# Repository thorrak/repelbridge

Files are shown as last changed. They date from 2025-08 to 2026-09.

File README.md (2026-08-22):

# RepelBridge - Cloud-free Mosquito Repelling

An ESP32-based controller that manages Thermacell Liv Repeller devices over WiFi without using the cloud. 

**NOTE** - This is an independent, third party project, and is not affiliated with Thermacell in any way. Thermacell and Thermacell LIV are trademarks of Thermacell Repellents, Inc. 

## Features

### Cloud Free
- Works entirely locally
- Integrates with Home Assistant over WiFi

### Dual Bus Support
- Independent control of two sets of up to five repellers
- Create "zones" of repellers that are controlled independently of one another

### Device Management
- Automatic device discovery and addressing (including for brand new devices)
- RGB LED color control and brightness adjustment
- Cartridge usage tracking and monitoring (WiFi only, see "limitations" below)
- Configurable auto-shutoff timers & cartridge warn timers

### Multi-Mode Operation
- **WiFi Mode**: Web-based REST API control for Home Assistant integration
- **Sniffer Mode**: Passive monitoring of RS-485 communications (for development)

### 100% Free & Open Source
- Open source firmware
- Open source hardware
- Open source Home Assistant integration
- All 100% free, and licensed under the (Apache 2.0 license)[LICENSE]

## Limitations

The communication protocol was reverse engineered from the official controller, and is not complete. Known to be missing is the built in "end of cartridge life" blinking, but other features not identified 

## Hardware

### Required Components
- **ESP32-S3 Microcontroller** - [ESP32-S3](https://www.seeedstudio.com/XIAO-ESP32S3-p-5627.html) recommended
- **Assembled RepelBridge PCB** - Design files available in this repo, including complete Bill of Materials. See [build guide](BUILDING.md) for details.
- **1x or 2x M12 4-pin A-coded Female Jacks** - [These](https://www.amazon.com/Waterproof-Connector-Bulkhead-Straight-Receptacle/dp/B0BVZDQYH5) or similar
- **Power Cable** - Standard [AC power cable](https://www.amazon.com/dp/B07C9D6CXY) of the appropriate length
- **Enclosure** - The one I used is [this one](https://www.amazon.com/dp/B0D97GQRGX), see [build guide](BUILDING.md) for more info

For complete build instructions, see the [build guide](BUILDING.md). 

For my build, material cost excluding shipping/taxes was appx. $97.14 per controller (each of which can manage two banks of repellers)

### Pin Connections (Xiao ESP32-S3)

#### Bus 0 (Primary)
- MAX3485 A/B → RS-485 bus 0 differential pair
- RO (Receive) → GPIO44 (UART RX)
- DI (Driver) → GPIO43 (UART TX)
- DE/RE (tied) → GPIO6 (Direction control)
- Power control → GPIO9

#### Bus 1 (Secondary)
- MAX3485 A/B → RS-485 bus 1 differential pair
- RO (Receive) → GPIO5
- DI (Driver) → GPIO7
- DE/RE (tied) → GPIO4 (Direction control)
- Power control → GPIO8

Pin assignments are defined as `BUS_X_*_PIN` build flags in [platformio.ini](platformio.ini) and can be overridden there.

### Communication Specs
- **Baud Rate**: 19,200
- **Format**: 8N1 (8 data bits, no parity, 1 stop bit)
- **Protocol**: RS-485 differential signaling
- **Packet Size**: 11 bytes fixed

## Building

### Prerequisites
- [PlatformIO](https://platformio.org/) installed
- ESP-IDF toolchain (fetched automatically by PlatformIO)
- Git for cloning dependencies

### Build Environment

The project ships a single PlatformIO environment targeting the Seeed XIAO ESP32-S3 with the ESP-IDF framework:

```bash
pio run -e esp32-s3-wifi
```

### Dependencies
Automatically managed by PlatformIO:
- `thorrak/esp_wifi_config` for WiFi provisioning (captive portal / Network Provisioning over BLE)
- `bblanchon/ArduinoJson` for REST API responses
- LittleFS (via ESP-IDF) for persistent settings storage

## Flashing

### Initial Flash
1. Connect the XIAO ESP32-S3 to your computer via USB-C
2. Build and upload firmware:
   ```bash
   pio run -e esp32-s3-wifi -t upload
   ```
3. Monitor serial output:
   ```bash
   pio device monitor -e esp32-s3-wifi
   ```

### WiFi Setup (First Boot)
1. Device creates WiFi access point: `RepelBridgeAP`
2. Connect to AP using password: `repelbridge`
3. Configure your WiFi network via captive portal (BLE provisioning is also supported)
4. Device will restart and connect to your network

### Mode Selection
Operational mode is selected at compile time via build flags in [platformio.ini](platformio.ini). The shipped `esp32-s3-wifi` environment defines `MODE_WIFI_CONTROLLER`. Alternate modes (`MODE_SNIFFER`, `MODE_CONTROLLER`) are still supported in the source and can be enabled by swapping the build flag.

## Home Assistant Integration

### Automatic Discovery
- Device advertises via mDNS as `_repelbridge._tcp.local.`
- Appears in Home Assistant as discovered integration
- Alternatively, manually add using device IP address

### Entities Created
For each bus (0 and 1):

**Light Entities**
- `light.repelbridge_bus_0` - RGB color and brightness control
- `light.repelbridge_bus_1` - RGB color and brightness control

**Switch Entities**
- `switch.repelbridge_bus_0_power` - Power on/off control
- `switch.repelbridge_bus_1_power` - Power on/off control

**Sensor Entities**
- `sensor.repelbridge_bus_0_runtime_hours` - Cartridge usage hours
- `sensor.repelbridge_bus_0_cartridge_life` - Remaining cartridge life %
- `sensor.repelbridge_bus_0_device_count` - Connected repeller count

**Configuration Entities**
- `number.repelbridge_bus_0_auto_shutoff` - Auto shutoff timer (seconds)
- `number.repelbridge_bus_0_cartridge_warning` - Cartridge warning threshold (hours)

### Services
- `repelbridge.reset_cartridge` - Reset cartridge runtime tracking

## Automation Examples

### Low Cartridge Warning

```yaml
automation:
  - alias: "RepelBridge Low Cartridge Warning"
    trigger:
      platform: numeric_state
      entity_id: sensor.repelbridge_bus_0_cartridge_life
      below: 10
    action:
      service: notify.mobile_app_your_phone
      data:
        message: "RepelBridge Bus 0 cartridge is running low ({{ states('sensor.repelbridge_bus_0_cartridge_life') }}% remaining)"
```

### Daily Schedule

```yaml
automation:
  - alias: "RepelBridge Daily Schedule"
    trigger:
      platform: time
      at: "20:00:00"
    action:
      - service: light.turn_on
        target:
          entity_id: light.repelbridge_bus_0
        data:
          rgb_color: [0, 213, 255]  # Cyan-blue
          brightness: 200
  
  - alias: "RepelBridge Turn Off"
    trigger:
      platform: time
      at: "06:00:00"
    action:
      service: light.turn_off
      target:
        entity_id: light.repelbridge_bus_0
```

### REST API Endpoints

Direct API access available at `http://device-ip/`:

**System Information**
- `GET /api/system/status` - Device status, uptime, WiFi info

**Bus Control** (replace `{0,1}` with bus number)
- `GET /api/bus/{0,1}/status` - Bus state and current settings
- `POST /api/bus/{0,1}/power` - Power control (JSON: `{"state": true/false}`)
- `POST /api/bus/{0,1}/brightness` - Brightness (JSON: `{"value": 0-255}`)
- `POST /api/bus/{0,1}/color` - RGB color (JSON: `{"red": 0-255, "green": 0-255, "blue": 0-255}`)

**Cartridge Management**
- `GET /api/bus/{0,1}/cartridge` - Usage stats and remaining life
- `POST /api/bus/{0,1}/cartridge/reset` - Reset runtime counter
- `GET /api/bus/{0,1}/auto_shutoff` - Get current auto-shutoff timer in minutes
- `POST /api/bus/{0,1}/auto_shutoff` - Set auto-shutoff timer (JSON: `{"minutes": 0-960}`)
- `GET /api/bus/{0,1}/warn_at` - Get current cartridge warning threshold in hours
- `POST /api/bus/{0,1}/warn_at` - Set warning threshold (JSON: `{"hours": 0-9999}`)

## Troubleshooting

### Device Not Discovered
- Ensure device is on the same network
- Check device is in WiFi mode (`MODE_WIFI_CONTROLLER`)
- Verify mDNS service `_repelbridge._tcp.local.` is broadcast

### Connection Issues
- Verify IP address is correct
- Check device web interface is accessible at `http://device-ip/api/system/status`
- Ensure firewall allows HTTP traffic on port 80

### Entity Updates
- Default update interval is 30 seconds
- Entities update automatically after control commands
- Check Home Assistant logs for API communication errors

## Support

For issues and feature requests, please use the GitHub repository issue tracker.

## License

This integration is provided under the Apache 2.0 license.

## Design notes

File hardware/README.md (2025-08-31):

# Hardware Source Files

This directory contains the hardware source files for a RepelBridge build.

## Assembly Template

To make assembling the enclosure easier, I created a very basic [Enclosure Hole Template](./Enclosure%20Hole%20Template.pdf) which can be printed and provides a 1:1 guide for where the holes should be drilled on the face of the enclosure.

Use of this template is optional, but I found it helpful.

## JLCPCB Fabrication Files

The files needed to order a fully assembled RepelBridge from [JLCPCB](https://jlcpcb.com/) are available in the `JLCPCB Files` directory. This includes:

- Gerbers in RepelBridge.zip
- "Bill of Materials" in bom.csv with JLCPCB/LCSC part numbers
- "Pick and Place" positions file in positions.csv

These files should be ready for use to order a RepelBridge PCB from JLCPCB. Full instructions for using them are available in the [build guide](../BUILDING.md)

**NOTE about M4 Screws** - JLCMC [sells](https://jlcmc.com/product/s/E02/EDLA/FA-%E7%B4%A7%E5%9B%BA%E9%9B%B6%E4%BB%B6-%E8%9E%BA%E9%92%89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) M4x6mm screws which they will ship alongside your PCB for a very reasonable price if ordered at the same time. I **highly** recommend ordering these together with the PCB as the cost will likely be at least an order of magnitude lower than ordering separately from other sources. 

## KiCad Source Files

If you want to modify the PCB design (for example, to leverage a different enclosure) the source [KiCad](https://www.kicad.org/) files are available in the `KiCad Source` directory. 

**NOTE** - If you edit the PCB in KiCad and use the JLCPCB tools to export the BoM/PnP files, you will need to manually edit the BoM and PnP files to add the second female pin header for the microcontroller (U2) as it will not be automatically added/placed.

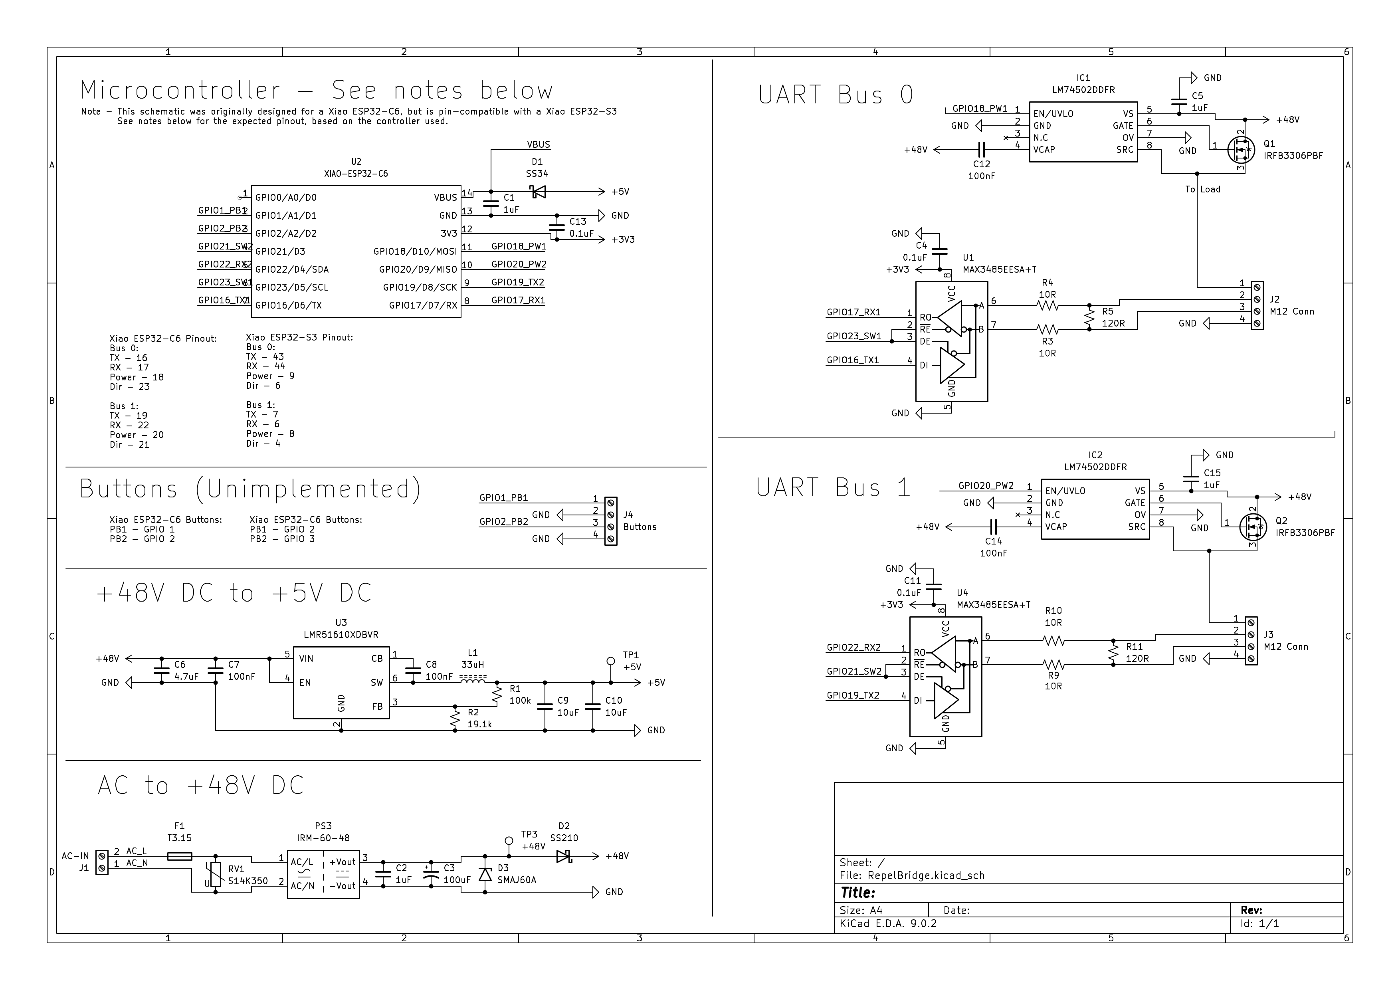
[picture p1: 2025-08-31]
img/schematic.png

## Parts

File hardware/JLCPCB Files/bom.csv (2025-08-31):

Designator | Footprint | Quantity | Value | LCSC Part #
C1 | 0603 | 1 | 1uF | C15849
C10, C9 | 0603 | 2 | 10uF | C19702
C11, C13, C4 | 0603 | 3 | 0.1uF | C14663
C12, C14, C7, C8 | 0805 | 4 | 100nF | C28233
C15, C2, C5 | 0805 | 3 | 1uF | C6119928
C3 | CP_Radial_D10.0mm_P5.00mm | 1 | 100uF | C2887235
C6 | 1210 | 1 | 4.7uF | C381466
D1 | D_SMA | 1 | SS34 | C8678
D2 | D_SMA | 1 | SS210 | C14996
D3 | D_SMA | 1 | SMAJ60A | C42394398
F1 | Fuse_8.5x4.0 | 1 | T3.15 | C354904
IC1, IC2 | SOT65P280X110-8N | 2 | LM74502DDFR | C3236215
J1 | TerminalBlock_Wuerth_691311400102_P7.62mm | 1 | AC-IN | C475104
J2, J3 | TerminalBlock_RND_205-00003_1x04_P5.00mm_Horizontal | 2 | M12 Conn | C3034542
J4 | TerminalBlock_RND_205-00003_1x04_P5.00mm_Horizontal | 1 | Buttons | C3034542
L1 | HPC8040NF | 1 | 33uH | C357084
PS3 | Converter_ACDC_MeanWell_IRM-60-xx_THT | 1 | IRM-60-48 | C5656542
Q1, Q2 | TO-220-3_Vertical | 2 | IRFB3306PBF | C2643
R1 | 0402 | 1 | 100k | C25741
R10, R3, R4, R9 | 0402 | 4 | 10R | C25077
R11, R5 | 0402 | 2 | 120R | C25079
R2 | 0402 | 1 | 19.1k | C52036
RV1 | RV_Disc_D15.5mm_W5.9mm_P7.5mm | 1 | S14K350 | C83535
TP1 | TestPoint_THTPad_D1.0mm_Drill0.5mm | 1 | +5V
TP3 | TestPoint_THTPad_D2.0mm_Drill1.0mm | 1 | +48V
U1, U4 | SOIC-8_3.9x4.9mm_P1.27mm | 2 | MAX3485EESA+T | C9943
U2,U2_2 | XIAO-ESP32C6-DIP | 1 | XIAO-ESP32-C6 | C25503116
U3 | SOT-23-6 | 1 | LMR51610XDBVR | C20539658

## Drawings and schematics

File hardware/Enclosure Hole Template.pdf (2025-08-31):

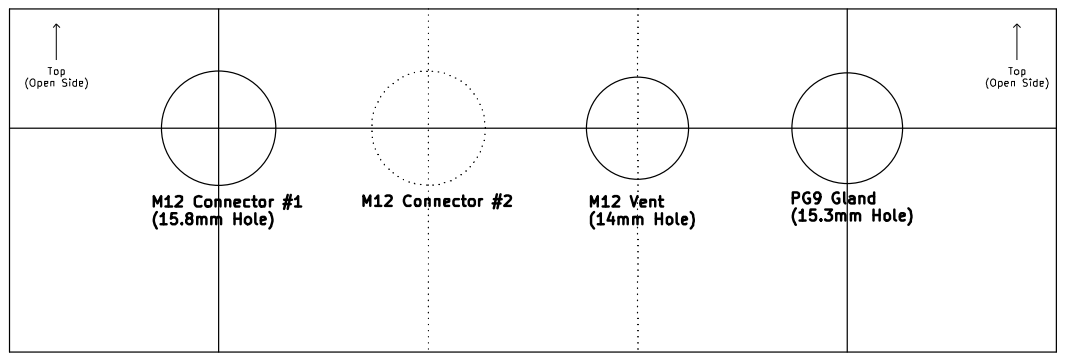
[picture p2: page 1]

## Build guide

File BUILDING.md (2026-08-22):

# Building a RepelBridge

## Introduction / About this Guide

This guide covers the steps that I used when building the RepelBridges that I have managing the Liv controllers in my home. Although most of the individual components I recommend can be replaced with similar alternatives, these replacements will almost certainly require changes elsewhere to the build - especially to the PCB design. I will try to provide some guidance as to why I selected certain components, but the expectation is that someone following this guide will purchase the components specified. If you make substitutions, you will be responsible for identifying other potential changes required on your own.

### Estimated Build Cost & Time

I estimate that my controllers - excluding tax, shipping, and tariffs - cost **$97.14** each to build - but it warrants mentioning that the minimum order quantity from JLCPCB for the PCB is 2. Each controller took about **20 minutes to assemble**, including drilling, wiring, and flashing. 

## Ordering the Parts

Most of the parts used in this build are dictated by the enclosure used and the PCB.

### Enclosure

The enclosure used for this build is [this one](https://www.amazon.com/dp/B0D97GQRGX) (the LeMotech IP67 6.9" x 4.9" x 3" Waterproof Junction Box). This junction is the perfect size to fit all of the required electronics, and is both dust and waterproof, meaning it should be safe in the elements. It has two 4mm heat set inserts already attached inside the case, providing an easy place to secure the PCB.

Although there are many similar junction boxes, the PCB was designed to fit this box's specific dimensions, including exact placement for the corner notches & screw holes. If you choose a different enclosure, you will need to adjust the PCB accordingly. 

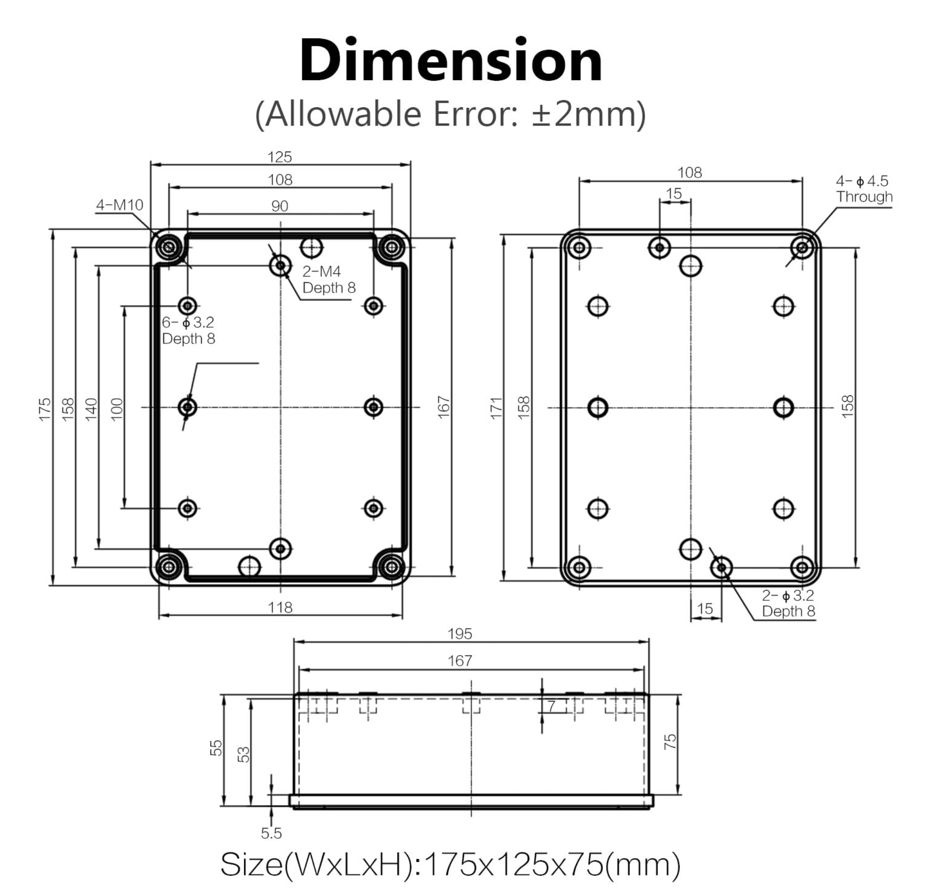
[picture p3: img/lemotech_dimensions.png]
The PCB was specifically designed for this enclosure Enclosure Dimensions


### PCB

The heart of a RepelBridge is the PCB. The PCB can be ordered _assembled_ from JLCPCB - which I **highly** recommend over attempting to assemble it yourself. All files necessary to order the PCB are available in the `hardware/JLCPCB Files` directory of this repo, including the files necessary for assembly.

#### Ordering the PCB

To order the PCB from JLCPCB, visit [https://www.jlcpcb.com/](https://www.jlcpcb.com/) and do the following:

1. Click **"Add gerber file"** and upload the gerbers (`RepelBridge.zip`)
2. On the following screen, after the PCB design loads, change **"Mark on PCB"** to **"Order Number(Specify Position)"**. Feel free to change the PCB color/other options if you choose.
3. Click the "switch" next to **"PCB Assembly"**.
4. Change **"Tooling holes"** to **"Added by Customer"**. Optionally change the PCBA Qty if you do not need 5 assembled PCBs.
5. Click **"Next"** to proceed to the gerber viewer. Click **"Next"** again to proceed to the "BoM" and "CPL" upload screen.
6. Upload the Bill of Materials CSV file (`bom.csv`) by clicking the **"Add BOM File"** button
7. Upload the Pick-and-Place Location CSV file (`positions.csv`) by clicking the **"Add CPL File"** button
8. Click **"Process BOM & CPL"**. If you get a message about "TP1,TP3" designators missing, just click **continue**. These are test points and do not/should not have hardware placed.
9. On the Bill of Materials list, review the list to ensure that all expected parts are populated. For parts J2, J3, and J4, JLCPCB will **require you to check the box** to populate the part. If any parts are out of stock, you may need to either find a replacement (be conscious of the parts you are replacing!) or wait until they are restocked to order.
10. Click **"Next"** to proceed to the 3D assembly viewer, where you can see a rendering of what the board will look like after assembly, and double check postioning of parts
11. Click **"Next"** again to receive the final quote.
12. Choose a product description from the drop down box (I used `Household Appliance > Household Electric Heating Equipment - HS Code 851690`)
13. Click **"Add to Cart"** and then proceed to place the order **after reading the note below about M4 screws**.

**NOTE about M4 Screws** - JLCMC [sells](https://jlcmc.com/product/s/E02/EDLA/FA-%E7%B4%A7%E5%9B%BA%E9%9B%B6%E4%BB%B6-%E8%9E%BA%E9%92%89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) M4x6mm screws which they will ship alongside your PCB for a very reasonable price if ordered at the same time. I **highly** recommend ordering these together as the cost will likely be at least an order of magnitude lower than ordering separately from other sources. 

#### About the PCB

The PCB incorporates a number of components to make the build work:
- A 120V/240V AC to 48VDC converter to power the board & the repellers on the bus
- A 48VDC to 5VDC converter to power the microcontroller 
- Circuitry to high-side switch the +48VDC to the repellers to physically disconnect them from power when not in use
- MAX3485 RS-485 Transceivers to allow communication with the repellers

The PCB also adds two screw terminals that could be used in the future to add buttons to toggle each of the busses on/off. Although the headers for these are populated, support does not exist in the firmware and these are not otherwise referenced in these build instructions.

**NOTE** - If you edit the PCB in KiCad and use the JLCPCB tools to export the BoM/PnP files, you will need to manually edit the BoM and PnP files to add the second female pin header for the microcontroller (U2) as it will not be automatically added/placed.

### Microcontroller

The RepelBridge is controlled via a microcontroller which serves as the "brains" of your build. The PCB design is intended to work with:

- [Xiao ESP32-S3](https://www.seeedstudio.com/Seeed-Studio-XIAO-ESP32S3-Pre-Soldered-p-6334.html)

The PCB is designed specifically for Seeed Studio's Xiao controllers. Seeed offers both pre-soldered and unsoldered versions of their boards - I recommend the pre-soldered version unless you are comfortable with a soldering iron.

### Other Components

In addition to the PCB, enclosure, and microcontroller there are a handful of other components required to build a RepelBridge -- especially given that we want it to remain waterproof.

- [AC power cable](https://www.amazon.com/dp/B07C9D6CXY) - You can select from a number of lengths, but make note of the gauge of the cable (16 vs. 14AWG). Larger gauge cable (higher number) will result in needing a larger cable gland
- [Cable gland](https://www.amazon.com/dp/B07DC7BH92) - I used a PG9 cable gland with a 16 AWG cable to keep the entry of my cable into the enclosure waterproof
- [Breather Vent](https://www.amazon.com/Dustproof-Waterproof-IP68-Breather-Screw/dp/B0DHGKN1TX) - A breather vent will prevent pressure differentials, while keeping your enclosure waterproof
- [1x or 2x M12 4-pin Type A Connectors](https://www.amazon.com/Waterproof-Connector-Bulkhead-Straight-Receptacle/dp/B0BVZDQYH5) - You will need one of these per bus you want to control
- [2x M4x6mm Screws](https://jlcmc.com/product/s/E02/EDLA/FA-%E7%B4%A7%E5%9B%BA%E9%9B%B6%E4%BB%B6-%E8%9E%BA%E9%92%89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) - For securing the PCB to the heat set inserts in the enclosure

## Assembly

Once you have received your microcontroller, enclosure, PCB, and other parts, you are ready to begin assembly. My recommendation for assembly order is:

1. Drill the holes in the enclosure
2. Attach the gland, vent, connectors, and power cable to the enclosure
3. Attach the PCB to the enclosure
4. Connect the wires to the PCB
5. Flash & connect the microcontroller to the PCB I recommend drilling the enclosure first, then attaching the gland/vent/connectors/power cable, connecting the PCB to the enclosure

### Drill the Enclosure

Before you beign, you will need to drill holes in your enclosure for the M12 connectors, cable gland, and vent:

- **M12 Connectors** - 16mm Clearance Holes
- **Vent** - 14mm Clearance Hole
- **Cable Gland** - 15.5mm (16mm) Clearance Hole

Although you can drill the holes in any order, I recommend that you place the M12 Connectors to the left of the case and the AC cable gland on the right. I have [a template](hardware/Enclosure%20Hole%20Template.pdf) in the hardware directory that you can print, cut out, and tape to the front of the enclosure to help act as a guide. If you do not plan to use both busses, you can omit one of the M12 connectors.

**TIP** - I recommend drilling a very small pilot hole at the "crosshairs" of the template before drilling the full size hole to help prevent the bit from "walking" across the face of the enclosure.

**NOTE** - The hole sizes listed above are very much approximate, as the drill bit I used - an imperial step drill bit - was absolutely not the right tool for the job. My research shows that the above are [likely the correct size](https://amesweb.info/Screws/Metric-Clearance-Hole-Chart.aspx) - if you try these and they work for you, please let me know.

### Assembling the Enclosure

After drilling the holes, insert the connectors, vent, and cable gland. Once the gland is secured to the enclosure, remove the "domed" front piece, and snake the AC power cable through the (loose) domed piece, and then through the rubber ring in the tines of the gland. Do not secure the domed piece until later, after you have connected the AC power to the PCB.

### Attach the PCB and Connect the Wires

Insert the PCB into the enclosure with the screw terminals facing the holes you just drilled. The PCB should be secured to the enclosure by using the 2 M4x6 screws. Screw the circuit board down into the brass heat set inserts on the left and right of the PCB using the appropriate hex key.

Once the PCB is secured, you are ready to connect the wires. Start by connecting the white and black wires from the AC power cable to the "AC IN" screw terminal on the far right side of the board:

- White Wire - Connects to "AC N"
- Black Wire - Connects to "AC L"
- Green Wire (if present) - Do not connect

**TIP** - It may be easier to secure the AC wires while the PCB is not screwed to the enclosure, and then re-secure it afterwards

After connecting the AC wiring you can slide the "domed" front piece of the cable gland up the cable and screw into the gland to tighten the rubber ring against the cable, which acts as both the waterproofing and as strain relief.

Next, you should connect the two M12 connectors. The wires to these connectors are typically color coded - assuming your connector has the standard colors, the typical wiring is:

- Brown wire - +48V
- Blue Wire - "A" Data Line
- Black Wire - "B" Data Line
- White Line - GND

**NOTE** - The wiring of the M12 connectors is _EXTREMELY_ important. Miswiring the connectors will burn out your repellers. 

### Flashing the Microcontroller

With your PCB wired, I recommend flashing the RepelBridge firmware to your microcontroller before plugging it in to the PCB.

**TODO** - Come back and write this section after adding RepelBridge to BrewFlasher. 

### Final Assembly

Plug the microcontroller into the female pin headers on the PCB with the USB-C port facing away from the enclosure wall - towards the screw terminals. Attach and secure the enclosure lid. Connect (and screw in) the connectors to the repellers - and plug your RepelBridge into the wall.

Congratulations - your RepelBridge is now built and ready to be set up. 

## Setup and Use

With your RepelBridge built, you will need to set it up to connect to WiFi and then in turn to Home Assistant.

**TODO** - Come back and write this section.

### Connecting to WiFi

### Installing the Home Assistant Integration

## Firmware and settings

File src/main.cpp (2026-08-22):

#include "esp_log.h"
#include "esp_timer.h"
#include "esp_vfs.h"
#include "esp_littlefs.h"
#include "nvs_flash.h"
#include "freertos/FreeRTOS.h"
#include "freertos/task.h"

#include "sniffer_mode.h"
#include "bus.h"

#ifdef MODE_WIFI_CONTROLLER
#include "wifi_controller.h"
#endif

static const char* TAG = "main";

#ifdef MODE_CONTROLLER
static uint32_t millis_now() {
  return (uint32_t)(esp_timer_get_time() / 1000);
}
#endif

// Global bus objects
Bus bus0(0);
Bus bus1(1);

static void app_setup() {
  vTaskDelay(pdMS_TO_TICKS(5000));
  ESP_LOGI(TAG, "Initializing...");

  // Initialize NVS flash (required for WiFi and other subsystems)
  esp_err_t nvs_ret = nvs_flash_init();
  if (nvs_ret == ESP_ERR_NVS_NO_FREE_PAGES || nvs_ret == ESP_ERR_NVS_NEW_VERSION_FOUND) {
    ESP_ERROR_CHECK(nvs_flash_erase());
    nvs_ret = nvs_flash_init();
  }
  ESP_ERROR_CHECK(nvs_ret);

  // Initialize LittleFS filesystem via VFS
  esp_vfs_littlefs_conf_t conf = {
    .base_path = "/littlefs",
    .partition_label = "spiffs",  // Uses the partition labeled "spiffs" in the partition table
    .format_if_mount_failed = true,
    .dont_mount = false,
  };

  esp_err_t lfs_ret = esp_vfs_littlefs_register(&conf);
  if (lfs_ret != ESP_OK) {
    ESP_LOGE(TAG, "Failed to initialize LittleFS (%s)", esp_err_to_name(lfs_ret));
  } else {
    ESP_LOGI(TAG, "LittleFS initialized successfully");
  }

#ifdef MODE_SNIFFER
  ESP_LOGI(TAG, "Starting in SNIFFER mode...");
  sniffer_setup();
#endif

#ifdef MODE_CONTROLLER
  ESP_LOGI(TAG, "Starting in CONTROLLER mode...");
  ESP_LOGI(TAG, "Initializing controller emulation...");

  vTaskDelay(pdMS_TO_TICKS(1000));

  // Initialize bus 0
  bus0.init();
  bus0.activate();  // Activate bus 0

  ESP_LOGI(TAG, "Running full startup sequence...");
  vTaskDelay(pdMS_TO_TICKS(1000));
  bus0.discover_repellers();
  ESP_LOGI(TAG, "Sent set as address...");
  vTaskDelay(pdMS_TO_TICKS(10000));

  bus0.discover_repellers();
  bus0.retrieve_serial_for_all();
  bus0.warm_up_all();

  ESP_LOGI(TAG, "Full startup sequence completed!");
#endif

#ifdef MODE_WIFI_CONTROLLER
  ESP_LOGI(TAG, "Starting in WIFI_CONTROLLER mode...");
  ESP_LOGI(TAG, "Initializing WiFi controller...");

  vTaskDelay(pdMS_TO_TICKS(1000));

  // Initialize WiFi controller
  wifi_controller_setup();

  ESP_LOGI(TAG, "WiFi controller initialization completed!");
#endif
}

static void app_loop() {
#ifdef MODE_SNIFFER
  sniffer_loop();
#endif

#ifdef MODE_CONTROLLER
    static bool ran_once = false;
    static uint32_t last_heartbeat = 0;
    uint32_t current_time = millis_now();

    bool heartbeat = false;
    if(!ran_once) {
      if (current_time - last_heartbeat > 15000) {
        ESP_LOGI(TAG, "Sending periodic heartbeat...");
        heartbeat = bus0.heartbeat_poll();
        last_heartbeat = current_time;
      }

      if(heartbeat) {
        vTaskDelay(pdMS_TO_TICKS(10000));
        bus0.change_led_color(0xA0, 0x00, 0x00);
        vTaskDelay(pdMS_TO_TICKS(10000));
        bus0.change_led_brightness(10);
        vTaskDelay(pdMS_TO_TICKS(10000));

        ESP_LOGI(TAG, "Shutting down all repellers...");
        bus0.shutdown_all();
        ran_once = true;
      }
    }

    vTaskDelay(pdMS_TO_TICKS(100));
#endif

#ifdef MODE_WIFI_CONTROLLER
    wifi_controller_loop();
    vTaskDelay(pdMS_TO_TICKS(1));
#endif
}

static void main_task(void*) {
  for (;;) {
    app_loop();
    vTaskDelay(pdMS_TO_TICKS(10));
  }
}

extern "C" void app_main(void) {
  app_setup();
  xTaskCreatePinnedToCore(main_task, "mainLoop", 8192, nullptr, 1, nullptr, 1);
}

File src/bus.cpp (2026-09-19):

#include "bus.h"
#include "known_packets.h"
#include "esp_log.h"
#include "esp_timer.h"
#include "driver/gpio.h"
#include "driver/uart.h"
#include "esp_vfs.h"
#include "esp_err.h"
#include "freertos/FreeRTOS.h"
#include "freertos/task.h"
#include "freertos/semphr.h"
#include <cinttypes>
#include <cstdio>
#include <sys/stat.h>

static const char* TAG = "bus";

// UART configuration
#define RS485_UART_NUM UART_NUM_1
#define RS485_BAUD_RATE 19200
#define RS485_BUF_SIZE 256

// How often the cartridge runtime counter is flushed to the filesystem while a
// bus is running. Flushing periodically rather than only on a graceful
// power-off bounds what a reset or power loss can discard to one interval.
#define CARTRIDGE_SAVE_INTERVAL_US (300ULL * 1000000ULL)

static uint32_t millis_now() {
  return (uint32_t)(esp_timer_get_time() / 1000);
}

// Both buses share RS485_UART_NUM, and the HTTP handlers (httpd task) drive the
// same Bus objects as the periodic poll in the main task. Every entry point that
// touches the UART or mutates bus state serialises on this recursive mutex, so a
// long transaction (discovery, warm-up) cannot have the UART pulled out from
// under it by the other task.
static SemaphoreHandle_t bus_lock() {
  static SemaphoreHandle_t lock = xSemaphoreCreateRecursiveMutex();
  return lock;
}

class BusLock {
public:
  BusLock() { xSemaphoreTakeRecursive(bus_lock(), portMAX_DELAY); }
  ~BusLock() { xSemaphoreGiveRecursive(bus_lock()); }
  BusLock(const BusLock&) = delete;
  BusLock& operator=(const BusLock&) = delete;
};

// Settings live behind their own short-held mutex so that reading or changing a
// stored value never queues behind a multi-second RS-485 transaction holding the
// bus lock. Lock order is always bus_lock() -> settings_lock(), never the
// reverse.
static SemaphoreHandle_t settings_lock() {
  static SemaphoreHandle_t lock = xSemaphoreCreateRecursiveMutex();
  return lock;
}

class SettingsLock {
public:
  SettingsLock() { xSemaphoreTakeRecursive(settings_lock(), portMAX_DELAY); }
  ~SettingsLock() { xSemaphoreGiveRecursive(settings_lock()); }
  SettingsLock(const SettingsLock&) = delete;
  SettingsLock& operator=(const SettingsLock&) = delete;
};

#define NO_ACTIVE_BUS 0xFF

static uint8_t active_bus_id = NO_ACTIVE_BUS;  // Which bus currently owns RS485_UART_NUM
static bool uart_installed = false;            // Whether the UART driver is currently installed


// Constructor - initialize bus with ID and set pin assignments
Bus::Bus(uint8_t id) : bus_id(id), bus_state(BUS_OFFLINE), 
                       warm_on_at(0), active_seconds_last_save_at(0),
                       last_polled(0),
                       power_request(BUS_POWER_REQ_NONE), repeller_total(0),
                       red(0x03), green(0xd5), blue(0xff), brightness(100), cartridge_active_seconds(0),
                       cartridge_warn_at_seconds(349200), auto_shut_off_after_seconds(18000) {
  // Set pin assignments based on bus ID
  if (bus_id == 0) {
    tx_pin = BUS_0_TX_PIN;
    rx_pin = BUS_0_RX_PIN;
    dir_pin = BUS_0_DIR_PIN;
    pow_pin = BUS_0_POW_PIN;
  } else if (bus_id == 1) {
#ifdef BUS_1_TX_PIN
    tx_pin = BUS_1_TX_PIN;
    rx_pin = BUS_1_RX_PIN;
    dir_pin = BUS_1_DIR_PIN;
    pow_pin = BUS_1_POW_PIN;
#else
    // Bus 1 not defined, set to invalid
    tx_pin = -1;
    rx_pin = -1;
    dir_pin = -1;
    pow_pin = -1;
#endif
  } else {
    // Invalid bus ID
    tx_pin = -1;
    rx_pin = -1;
    dir_pin = -1;
    pow_pin = -1;
  }
}

// Initialize the bus (set the initial state for the pins)
void Bus::init() {
  BusLock lock;

  if (dir_pin == -1) {
    ESP_LOGE(TAG, "Bus %d: Invalid pin configuration", bus_id);
    bus_state = BUS_ERROR;
    return;
  }

  bus_state = BUS_OFFLINE;

  gpio_set_direction((gpio_num_t)dir_pin, GPIO_MODE_OUTPUT);
  gpio_set_level((gpio_num_t)dir_pin, 0);  // Start in receive mode

  if(pow_pin != -1) {
    ESP_LOGI(TAG, "Bus %d: output pow pin low", bus_id);
    gpio_set_direction((gpio_num_t)pow_pin, GPIO_MODE_OUTPUT);
    gpio_set_level((gpio_num_t)pow_pin, 0);  // Start the bus off powered off
  }

  // Load settings from filesystem
  load_settings();
}

// Give this bus ownership of the shared RS-485 UART. Does not touch bus power.
// Tracks driver installation separately from ownership: powerdown() releases
// ownership, and the previous code then skipped the delete and re-installed on
// top of a live driver, which fails with ESP_ERR_INVALID_STATE.
bool Bus::configure_uart() {
  if (tx_pin == -1 || rx_pin == -1 || dir_pin == -1) {
    ESP_LOGE(TAG, "Bus %d: Invalid pin configuration", bus_id);
    bus_state = BUS_ERROR;
    return false;
  }

  if (active_bus_id == bus_id && uart_installed) {
    return true;  // Already ours
  }

  if (uart_installed) {
    uart_driver_delete(RS485_UART_NUM);
    uart_installed = false;
    active_bus_id = NO_ACTIVE_BUS;
  }

  uart_config_t uart_config = {
    .baud_rate = RS485_BAUD_RATE,
    .data_bits = UART_DATA_8_BITS,
    .parity = UART_PARITY_DISABLE,
    .stop_bits = UART_STOP_BITS_1,
    .flow_ctrl = UART_HW_FLOWCTRL_DISABLE,
    .source_clk = UART_SCLK_DEFAULT,
  };

  esp_err_t err = uart_param_config(RS485_UART_NUM, &uart_config);
  if (err == ESP_OK) {
    err = uart_set_pin(RS485_UART_NUM, tx_pin, rx_pin, UART_PIN_NO_CHANGE, UART_PIN_NO_CHANGE);
  }
  if (err == ESP_OK) {
    err = uart_driver_install(RS485_UART_NUM, RS485_BUF_SIZE, 0, 0, NULL, 0);
  }
  if (err != ESP_OK) {
    ESP_LOGE(TAG, "Bus %d: UART setup failed (%s)", bus_id, esp_err_to_name(err));
    bus_state = BUS_ERROR;
    return false;
  }

  uart_installed = true;
  active_bus_id = bus_id;
  uart_flush_input(RS485_UART_NUM);  // Clear any existing data

  ESP_LOGI(TAG, "Bus %d: took ownership of the RS-485 UART", bus_id);
  return true;
}

// Activate the bus (Power on the bus (if unpowered) and configure UART)
void Bus::activate() {
  BusLock lock;

  if(bus_state == BUS_ERROR) {
    // Deliberately not calling powerdown() here - it resets bus_state to
    // BUS_OFFLINE, which made a permanently misconfigured bus look recoverable
    // and let the next activate() drive GPIO -1.
    ESP_LOGE(TAG, "Bus %d: Cannot activate bus in error state", bus_id);
    return;
  }

  if(dir_pin == -1) {
    ESP_LOGE(TAG, "Bus %d: Invalid pin configuration", bus_id);
    bus_state = BUS_ERROR;
    return;
  }

  gpio_set_level((gpio_num_t)dir_pin, 0);  // Start in receive mode

  if(bus_state == BUS_OFFLINE) {
    if(pow_pin != -1) {
      gpio_set_level((gpio_num_t)pow_pin, 1);  // Power on the bus
      vTaskDelay(pdMS_TO_TICKS(1000)); // Allow 1s for bus to power up
    }
    bus_state = BUS_POWERED;
  }

  configure_uart();
}
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

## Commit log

2025-06-23 Refactor tx_controller to utilize Packet class for transmission and reception
    - Removed static packet identification and reception functions, replacing them with a more modular Packet class.
    - Updated tx_controller_init to remove direction pin parameter and initialize RS-485 communication.
    - Simplified packet transmission functions to use Packet class methods for sending various commands.
    - Implemented discover_repellers function to identify devices on the bus and retrieve their serial numbers.
    - Added warm_up_all function to send warmup commands to all discovered repellers.
    - Updated header file to reflect changes in function signatures and added new function declarations.
2025-06-23 Add ESP32-C6 and dual bus support
2025-06-29 feat: Implement Zigbee color dimmable light functionality
    - Updated platform version in platformio.ini to support Zigbee features.
    - Added ZBCDL (Zigbee Color Dimmable Light) class for managing color and brightness.
    - Introduced Zigbee power control methods in Bus class for managing device states.
    - Enhanced bus.h to include Zigbee power control methods.
    - Modified main.cpp to support a new Zigbee controller mode.
    - Created zigbee_controller.cpp and zigbee_controller.h for managing Zigbee devices.
2025-06-29 feat: Optimize RGB and brightness setting methods to prevent unnecessary updates and add logging for unchanged values feat: Implement cartridge runtime tracking and reporting in Zigbee device with cu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
    [bus.cpp]
2025-07-25 Use GUID to name device
2025-07-25 Update LED color & brightness on device
2025-07-26 Fix brightness handling for HTTP
    [bus.cpp, main.cpp]
2025-07-27 Replace ESP32-C6 with ESP32-S3 for WiFi config
2025-08-31 Add hardware source files
    [RepelBridge.kicad_pcb, RepelBridge.kicad_sch, bom.csv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]
2025-08-31 Add partition definition
    [4mb_inc_ota.csv]
2026-04-05 Convert to ESP-IDF
    [zigbee_zczr.csv]
2026-04-05 Drop Zigbee in favor of pure WiFi
    [zigbee_zczr.csv]
2026-05-16 Switch `esp_wifi_config` to use idf_component.yml instead of platformio.ini
2026-06-01 Add browser-based control UI served from device
    Serve a single-page control UI from LittleFS so the device is usable
    without Home Assistant. Adds a static-file handler in wifi_controller
    (gzip-aware, SPA fallback, path-traversal guard) registered on a /*
    wildcard after the /api routes, and bumps max_uri_handlers to fit.
2026-08-22 Firmware review pass: bus concurrency, buffer and lifecycle fixes
    Serialise Bus behind a recursive mutex. Both buses share UART_NUM_1 and the
    HTTP handlers drive the same Bus objects as the periodic poll in the main
    task, so a poll on one bus could call uart_driver_delete() while the other
    was inside uart_read_bytes(). Settings sit behind a second, short-held mutex
    (ordered after the bus lock) so reading or storing a value never queues
    behind a multi-second RS-485 transaction.
    Defer power changes to the main loop. POST /api/bus/N/power now queues the
    request and returns at once instead of blocking httpd for the whole discovery
    and warm-up sequence; poll() services it, and the status reporte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
    [bus.cpp, main.cpp, sniffer_mode.cpp]
2026-08-23 Fix boot abort, mDNS registration order, and SoftAP teardown
    Initialise esp_netif before starting the HTTP server. wifi_setup_init()
    starts httpd and hands the handle to wifi_cfg_init(), so the listening
    socket is opened before the library gets a chance to call esp_netif_init()
    itself. Nothing had brought lwIP up at that point and httpd_server_init()
    aborted in tcpip_send_msg_wait_sem with "Invalid mbox", every boot. The
    call was dropped in e2c50d2 when WiFi setup moved out of wifi_controller.cpp;
    esp_wifi_config calls it too, tolerating ESP_ERR_INVALID_STATE, so doing it
    here first is free.
    Register mDNS before the STA connects. mdns_priv_netif_init() only installs
    IP_EVENT/WIFI_EVENT hand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
2026-09-19 State current behavior in comments instead of past behavior
    Four comments explained the code by describing the bug it used to have.
    The reasoning is kept, reframed as what the code does now: the cartridge
    flush interval, transmit() not energising an idle bus, discovery resetting
    known repellers to OFFLINE, and load_settings() reading into a scratch copy.
    [bus.cpp]
